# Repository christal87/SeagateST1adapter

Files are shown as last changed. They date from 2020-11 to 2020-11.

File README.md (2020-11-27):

# SeagateST1adapter

This is a quick and dirty 40 or 44 pin IDE adapter for Seagate ST1 drives with ATA Flex interface.  
These drives were common in mid- to high-end portable music players between 2000-2008.  
  
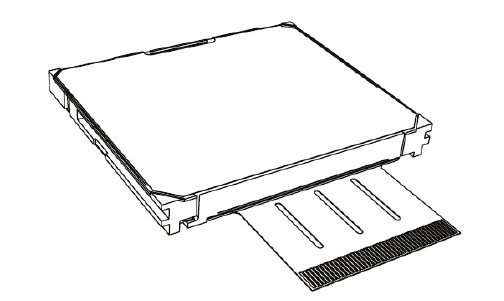
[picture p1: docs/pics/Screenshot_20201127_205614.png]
Illustration
    
  
My PCB was quickly routed with FreeRouting using an exported Specctra session file from KiCAD.  
I have tested raw and unpartitioned writes with dd, filling an ST650211FX disk with about 1GB of zeroes shown 3MB/s throughtput at an average.  
  
Check out the wikipedia article about these disks [here](https://en.wikipedia.org/wiki/Seagate_ST1).  
Also Hans-Jürgen Reggel experimented with them awhile ago. Which you can see [here](http://www.hjreggel.net/hdtechdat/hd-seagate.html).  
  
##### Known ST1 HDDs with ATA Flex interface:
  
- ST625211FX (2.5GB) (2004)
- ST650211FX (5GB) (2004)
- ST64022FX (4GB) (2005)
- ST66022FX (6GB) (2005)
- ST68022FX (8GB) (2005)

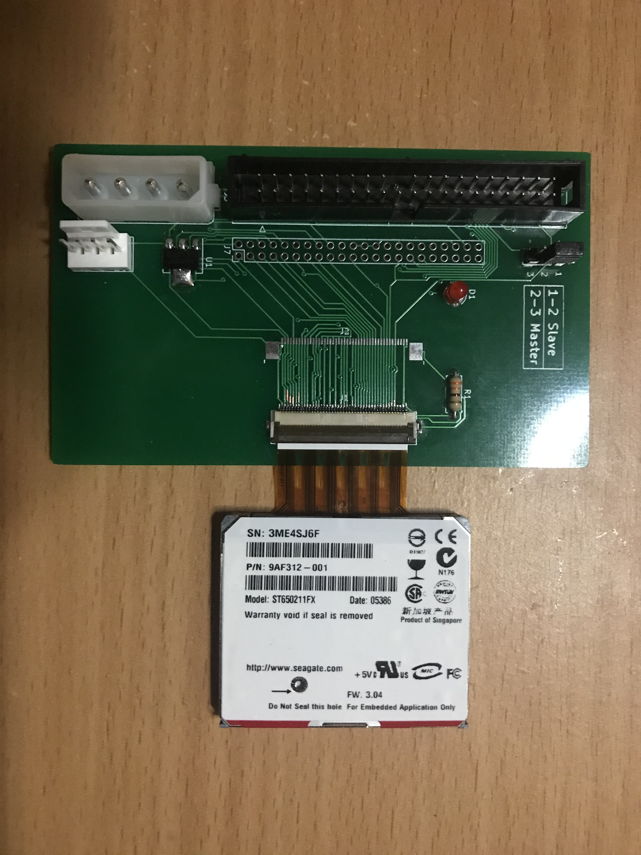
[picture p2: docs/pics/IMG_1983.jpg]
  
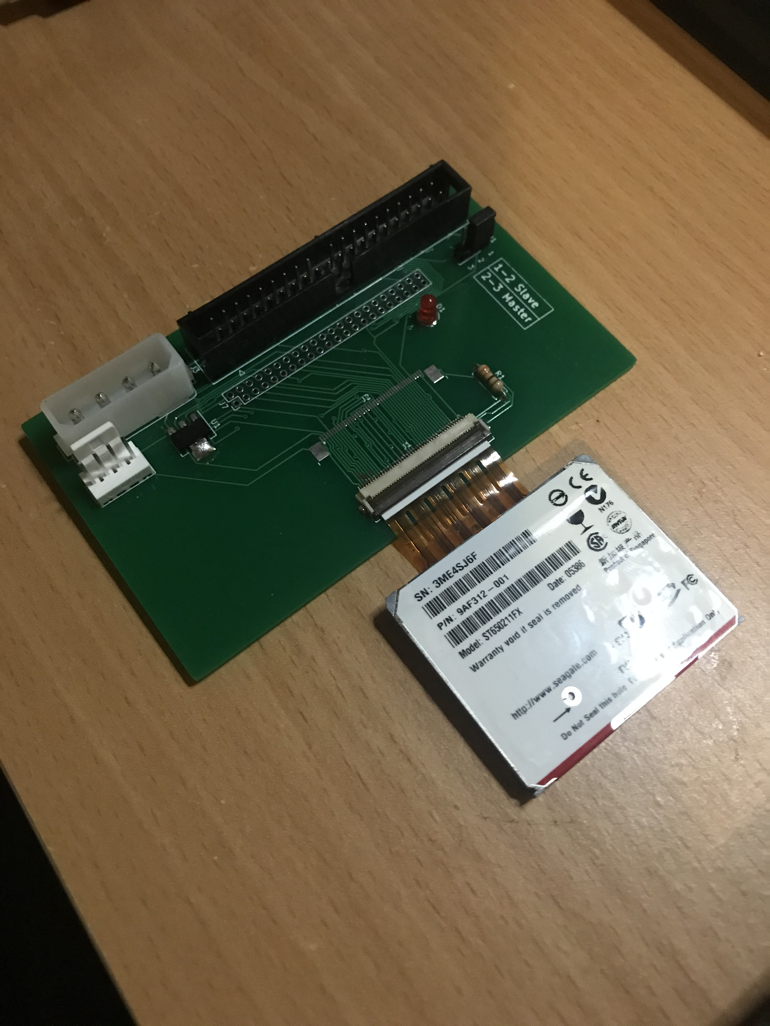
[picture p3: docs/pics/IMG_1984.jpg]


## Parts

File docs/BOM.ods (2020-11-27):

Designator | Brand | PN | Qty | Mouser SKU | Farnell SKU | Mouser URL | Farnell URL
J1 | Hirose | FH12-45S-0.5SH(55) | 1 | 798-FH12-45S-0.5SH55 | 2427723 | https://hu.mouser.com/ProductDetail/Hirose-Connector/FH12-45S-05SH55 | https://hu.farnell.com/hirose-hrs/fh12-45s-0-5sh-55/connector-ffc-fpc-rcpt-45pos-1row/dp/2427723
J2 | AMP – TE | 4-1734839-5 | 1 | 571-4-1734839-5 | 2967797 | https://hu.mouser.com/ProductDetail/TE-Connectivity/4-1734839-5 | https://hu.farnell.com/amp-te-connectivity/4-1734839-5/fpc-conn-0-5mm-pitch-t-c-45p/dp/2967797
J3 | 3M | 30340-6002HB | 1 | 517-30340-6002 | 2668422 | https://hu.mouser.com/ProductDetail/3M-Electronic-Solutions-Division/30340-6002HB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 | https://hu.farnell.com/3m/30340-6002hb/connector-header-40pos-2row-2/dp/2668422
J4 | Molex | 22-27-2041 | 1 | 538-22-27-2041 | 9731164 | https://hu.mouser.com/ProductDetail/Molex/22-27-2041 | https://hu.farnell.com/molex/22-27-2041/connector-header-4pos-1row-2-54mm/dp/9731164
J5 | AMP – TE | 350211-1 | 1 | 571-3502111 | 148086 | https://hu.mouser.com/ProductDetail/TE-Connectivity-AMP/350211-1 | https://hu.farnell.com/amp-te-connectivity/350211-1/header-vertical-solder-1-row-4way/dp/148086
J7 (US) | Samtec | FTSH-122-04-F-D | 1 | 200-FTSH12204FD | N/A | https://hu.mouser.com/ProductDetail/Samtec/FTSH-122-04-F-D?qs=rU5fayqh%252BE3yjEEyc3lvlQ%3D%3D | N/A
J7 (EU) | AMP – TE | 1-104068-4 | 1 | N/A | 2977178 | N/A | https://hu.farnell.com/amp-te-connectivity/1-104068-4/connector-header-44pos-2row-1/dp/2977178
JP1 Pins | WÜRTH ELEC | 61300311121 | 1 | 710-61300311121 | 2356154 | https://hu.mouser.com/ProductDetail/Wurth-Elektronik/61300311121 | https://hu.farnell.com/wurth-elektronik/61300311121/header-2-54mm-pin-tht-vertical/dp/2356154
JP1 Bridge | HARWIN | M7687-05 | 1 | 855-M7687-05 | 3218491 | https://hu.mouser.com/ProductDetail/Harwin/M7687-05 | https://hu.farnell.com/harwin/m7687-05/jumper-socket-10mm-blue/dp/3218491
U1 | TI | LM1117MP-3.3/NOPB | 1 | 926-LM1117MP-3.3NOPB | 3007502 | https://hu.mouser.com/ProductDetail/Texas-Instruments/LM1117MP-33-NOPB?qs=X1J7HmVL2ZFn4x9DZ4T2hA%3D%3D | https://hu.farnell.com/texas-instruments/lm1117mp-3-3-nopb/ldo-fixed-3-3v-0-8a-sot-223-4/dp/3007502
D1 | Broadcom – Avago | HLMP-1301 | 1 | 630-HLMP-1301 | 1003196 | https://hu.mouser.com/ProductDetail/Broadcom-Avago/HLMP-1301 | https://hu.farnell.com/broadcom-limited/hlmp-1301/led-3mm-red-3-4mcd-626nm/dp/1003196
R1 (EU) | Multicomp Pro | MCF 0.25W 330R | 1 | N/A | 9339418 | N/A | https://hu.farnell.com/multicomp/mcf-0-25w-330r/res-330r-5-250mw-axial-carbon/dp/9339418
R1 (US) | Yageo | MFR-25FTE52-330R | 1 | 603-MFR-25FTE52-330R | N/A | https://hu.mouser.com/ProductDetail/Yageo/MFR-25FTE52-330R | N/A

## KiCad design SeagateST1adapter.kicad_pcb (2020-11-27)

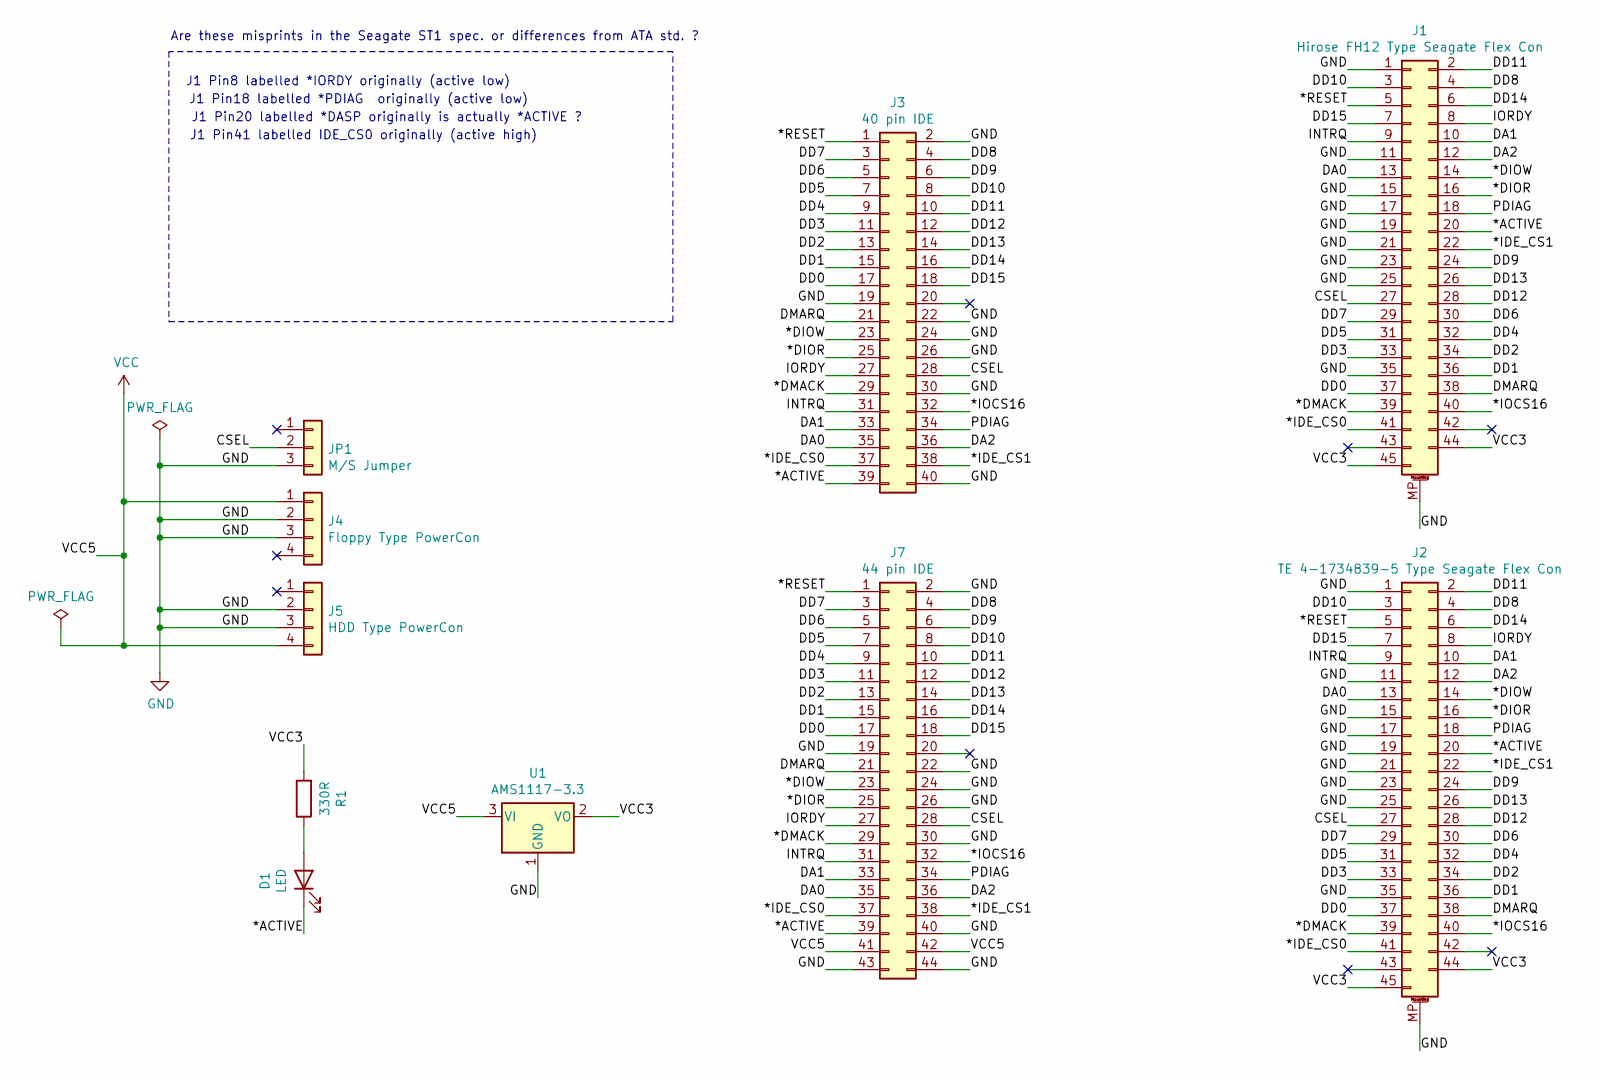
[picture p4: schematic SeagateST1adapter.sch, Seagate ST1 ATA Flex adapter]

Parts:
D1: LED; LED_D3.0mm
J1: Hirose FH12 Type Seagate Flex Con; Hirose_FH12-45S-0.5SH_1x45-1MP_P0.50mm_Horizontal
J2: TE 4-1734839-5 Type Seagate Flex Con; TE_4-1734839-5_1x45-1MP_P0.5mm_Horizontal
J3: 40 pin IDE; IDC-Header_2x20_P2.54mm_Vertical
J4: Floppy Type PowerCon; Molex_KK-254_AE-6410-04A_1x04_P2.54mm_Vertical
J5: HDD Type PowerCon; TE_MATE-N-LOK_350211-1_1x04_P5.08mm_Vertical
J7: 44 pin IDE; PinHeader_2x22_P2.00mm_Vertical
JP1: M/S Jumper; PinHeader_1x03_P2.54mm_Vertical
R1: 330R; R_Axial_DIN0207_L6.3mm_D2.5mm_P7.62mm_Horizontal
U1: AMS1117-3.3; SOT-223-3_TabPin2

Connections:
/*ACTIVE: D1.1 (K), J1.20, J2.20, J3.39, J7.39
/*DIOR: J1.16, J2.16, J3.25, J7.25
/*DIOW: J1.14, J2.14, J3.23, J7.23
/*DMACK: J1.39, J2.39, J3.29, J7.29
/*IDE_CS0: J1.41, J2.41, J3.37, J7.37
/*IDE_CS1: J1.22, J2.22, J3.38, J7.38
/*IOCS16: J1.40, J2.40, J3.32, J7.32
/*RESET: J1.5, J2.5, J3.1, J7.1
/CSEL: J1.27, J2.27, J3.28, J7.28, JP1.2
/DA0: J1.13, J2.13, J3.35, J7.35
/DA1: J1.10, J2.10, J3.33, J7.33
/DA2: J1.12, J2.12, J3.36, J7.36
/DD0: J1.37, J2.37, J3.17, J7.17
/DD1: J1.36, J2.36, J3.15, J7.15
/DD2: J1.34, J2.34, J3.13, J7.13
/DD3: J1.33, J2.33, J3.11, J7.11
/DD4: J1.32, J2.32, J3.9, J7.9
/DD5: J1.31, J2.31, J3.7, J7.7
/DD6: J1.30, J2.30, J3.5, J7.5
/DD7: J1.29, J2.29, J3.3, J7.3
/DD8: J1.4, J2.4, J3.4, J7.4
/DD9: J1.24, J2.24, J3.6, J7.6
/DD10: J1.3, J2.3, J3.8, J7.8
/DD11: J1.2, J2.2, J3.10, J7.10
/DD12: J1.28, J2.28, J3.12, J7.12
/DD13: J1.26, J2.26, J3.14, J7.14
/DD14: J1.6, J2.6, J3.16, J7.16
/DD15: J1.7, J2.7, J3.18, J7.18
/DMARQ: J1.38, J2.38, J3.21, J7.21
/INTRQ: J1.9, J2.9, J3.31, J7.31
/IORDY: J1.8, J2.8, J3.27, J7.27
/PDIAG: J1.18, J2.18, J3.34, J7.34
/VCC3: J1.44, J1.45, J2.44, J2.45, R1.2, U1.2 (VO)
GND: J1.1, J1.11, J1.15, J1.17, J1.19, J1.21, J1.23, J1.25, J1.35, J1.MP (MountPin), J2.1, J2.11, J2.15, J2.17, J2.19, J2.21, J2.23, J2.25, J2.35, J2.MP (MountPin), J3.2, J3.19, J3.22, J3.24, J3.26, J3.30, J3.40, J4.2, J4.3, J5.2, J5.3, J7.2, J7.19, J7.22, J7.24, J7.26, J7.30, J7.40, J7.43, J7.44, JP1.3, U1.1 (GND)
unnamed: D1.2 (A), R1.1
VCC: J4.1, J5.4, J7.41, J7.42, U1.3 (VI)

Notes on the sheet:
J1 Pin8 labelled *IORDY originally (active low)
J1 Pin18 labelled *PDIAG originally (active low)
J1 Pin20 labelled *DASP originally is actually *ACTIVE ?
J1 Pin41 labelled IDE_CS0 originally (active high)
Are these misprints in the Seagate ST1 spec. or differences from ATA std. ?

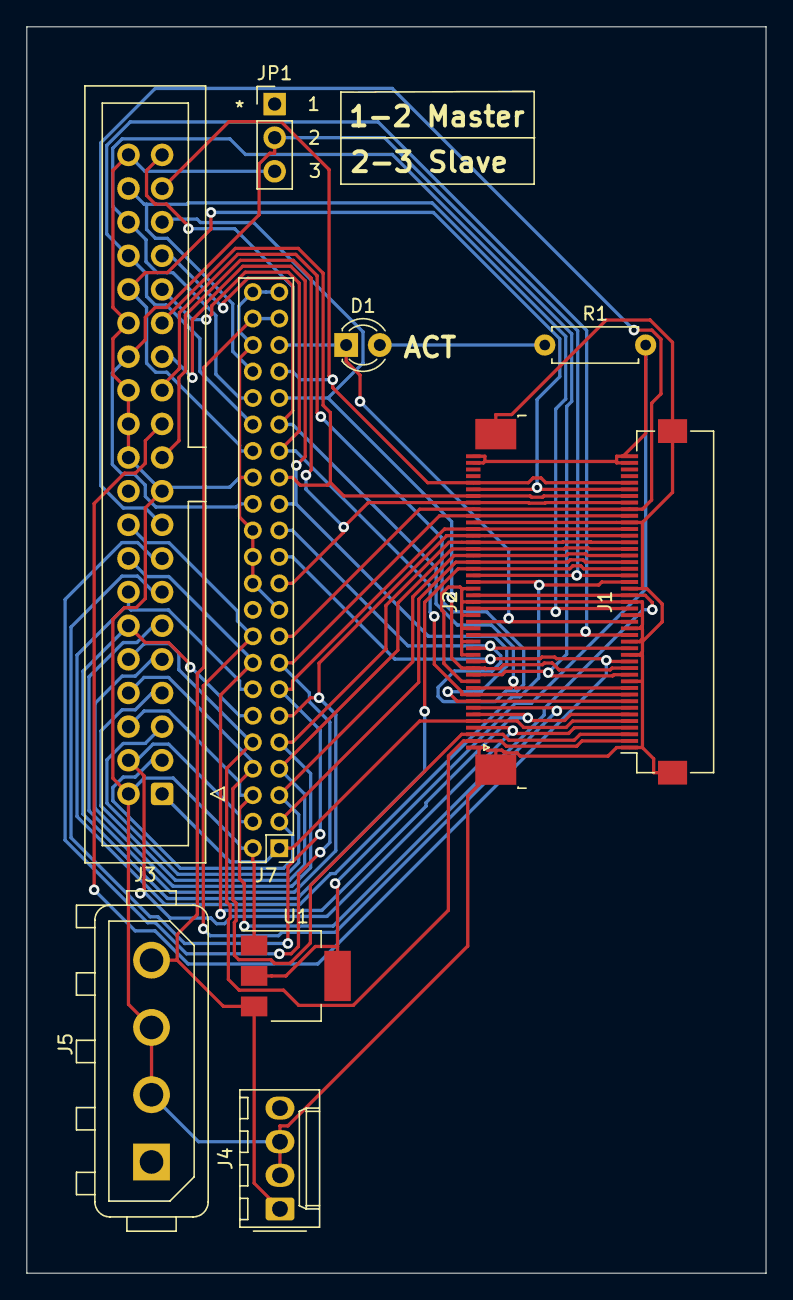
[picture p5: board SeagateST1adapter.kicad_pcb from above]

Board: 2 copper layers, 55.8 x 94.1 mm, 10 parts (0 on the bottom side), 36 nets.
